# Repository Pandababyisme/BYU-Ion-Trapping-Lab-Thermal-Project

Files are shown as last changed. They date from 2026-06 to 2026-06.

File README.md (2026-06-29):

# BYU-Ion-Trapping-Lab-Thermal-Project
Hi, I am Xiao Li. This is the project I worked on during summer of 2026, which is a thermal monitoring solution for an ion trapping quantum information processing lab. I will provide as detailed steps as I can here. Hopefully, it can be useful one day for you. :)

## 1. Preview
   In an ion trapping lab, different components and machines coperate as a whole to function the state-of-art quantum information process. While this happening, constronted by phsical phnominone, heat drfit will occur. And for our propuse we want to monitor the thermal information to get a better idea of what is going on.

## 2. Solution
   We proposed a solution of a system that consists one arduino, six maxchips, six pt100 sensors, and various supporting parts. In the following, we will step into more detailed description of different components, introductions of the way to make them work, assemble individual parts into a system and mislinious steps of supporting.

### 2.1)Arduino 
As the introduction, we will need one Arduino. The one we used is Arduino UNO R4 minima, personally I think it is a pretty powerful and realiable source for this project. In our solution, an arduino will role as the brain in system, which will suffit the tasks as: data collection, communicating with six maxchips via SPI protocal, transimitting data to our computer, etc. And the way we implement those tasks is through Arduino IDE. By uploading proper code to Arduino, it will perform the way as desired, and complete tasks. So we will include a Arduino IDE code file in this repository as an example of one solution. 

#### 2.11) Code design of the Arduino

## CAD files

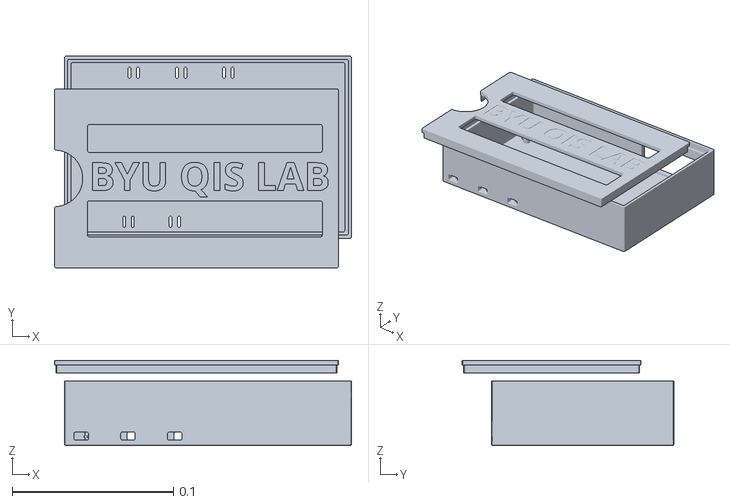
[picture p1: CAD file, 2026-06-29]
Part Studio 1.stl
0.184 x 0.131 x 0.053

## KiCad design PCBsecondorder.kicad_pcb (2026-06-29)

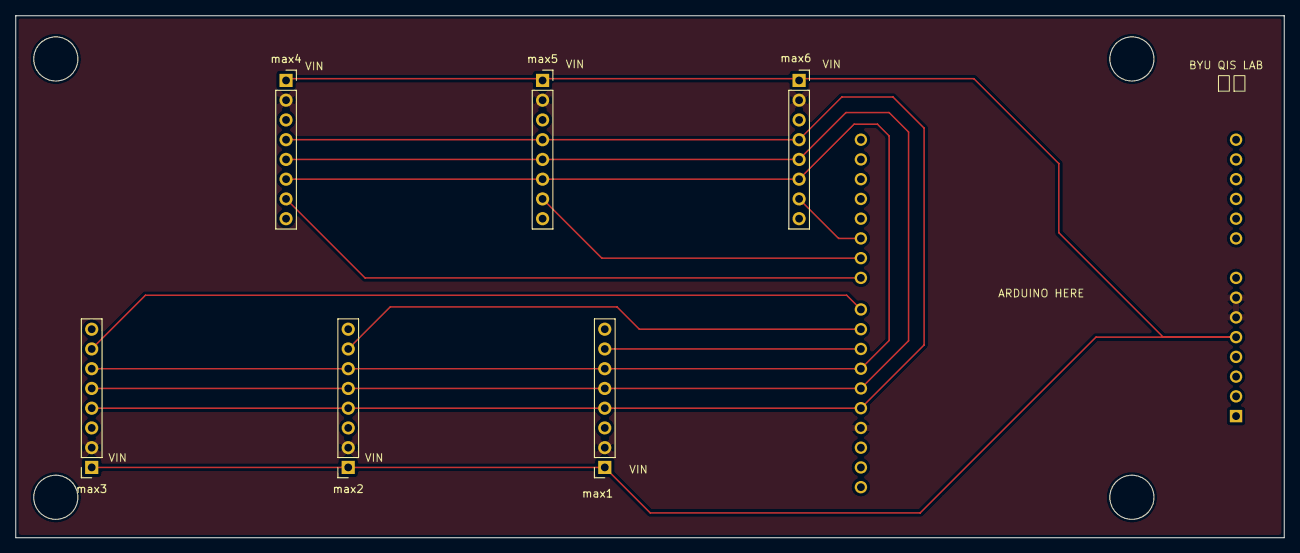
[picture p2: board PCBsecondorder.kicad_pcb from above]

Board: 2 copper layers, 163.2 x 67.1 mm, 7 parts (1 on the bottom side), 11 nets.

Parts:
A1: Arduino_UNO_R4; Arduino_UNO_R3
max1, max2, max3, max4, max5, max6: Conn_01x08; PinSocket_1x08_P2.54mm_Vertical

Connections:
/5V: A1.5 (+5V), max1.1, max2.1, max3.1, max4.1, max5.1, max6.1
/CLK: A1.28 (D13), max1.4, max2.4, max3.4, max4.4, max5.4, max6.4
/CS1: A1.25 (D10), max1.7
/CS2: A1.24 (D9), max2.7
/CS3: A1.23 (D8), max3.7
/CS4: A1.22 (D7), max4.7
/CS5: A1.21 (D6), max5.7
/CS6: A1.20 (D5), max6.7
/GND: A1.6 (GND), A1.7 (GND), A1.29 (GND), max1.2, max2.2, max3.2, max4.2, max5.2, max6.2
/SDI: A1.26 (D11), max1.6, max2.6, max3.6, max4.6, max5.6, max6.6
/SDO: A1.27 (D12), max1.5, max2.5, max3.5, max4.5, max5.5, max6.5

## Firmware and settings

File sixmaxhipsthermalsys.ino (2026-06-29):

#include <Adafruit_MAX31865.h>
#include <SPI.h>

// -------------------------------
// Output mode
// -------------------------------
#define MODE_DEBUG   0
#define MODE_PLOTTER 1
#define MODE_CSV     2

// Choose one mode here:
// MODE_CSV     = output Max1 to Max6 for Python/Excel
// MODE_PLOTTER = show six curves in Serial Plotter
// MODE_DEBUG   = detailed Serial Monitor output
#define OUTPUT_MODE 2

// -------------------------------
// CS pins for the 6 MAX31865 chips
// Sensor 1 -> CS 10
// Sensor 2 -> CS 9
// Sensor 3 -> CS 8
// Sensor 4 -> CS 7
// Sensor 5 -> CS 6
// Sensor 6 -> CS 5
// -------------------------------
const int CS_PINS[6] = {10, 9, 8, 7, 6, 5};

// PT100 settings
#define RREF      430.0
#define RNOMINAL 100.0

// -------------------------------
// Two-point calibration values
// -------------------------------
float refLow = 10.8;
float refHigh = 92.8;

float rawLow[6] = {
  11.66,  // Max1 raw low temp
  11.55,  // Max2 raw low temp
  11.62,  // Max3 raw low temp
  11.66,  // Max4 raw low temp
  11.72,  // Max5 raw low temp
  11.89   // Max6 raw low temp
};

float rawHigh[6] = {
  92.75,  // Max1 raw high temp
  92.65,  // Max2 raw high temp
  92.78,  // Max3 raw high temp
  92.89,  // Max4 raw high temp
  92.27,  // Max5 raw high temp
  92.58   // Max6 raw high temp
};

// Calibration equation:
// calibratedTemp = slope * rawTemp + intercept
float slope[6];
float intercept[6];

// -------------------------------
// Create 6 MAX31865 objects
// -------------------------------
Adafruit_MAX31865 max1 = Adafruit_MAX31865(CS_PINS[0]);
Adafruit_MAX31865 max2 = Adafruit_MAX31865(CS_PINS[1]);
Adafruit_MAX31865 max3 = Adafruit_MAX31865(CS_PINS[2]);
Adafruit_MAX31865 max4 = Adafruit_MAX31865(CS_PINS[3]);
Adafruit_MAX31865 max5 = Adafruit_MAX31865(CS_PINS[4]);
Adafruit_MAX31865 max6 = Adafruit_MAX31865(CS_PINS[5]);

Adafruit_MAX31865* sensors[6] = {
  &max1, &max2, &max3, &max4, &max5, &max6
};

// -------------------------------
// Calculate calibration constants
// -------------------------------
void calculateCalibration() {
  for (int i = 0; i < 6; i++) {
    float denominator = rawHigh[i] - rawLow[i];

    if (denominator > -0.001 && denominator < 0.001) {
      slope[i] = 1.0;
      intercept[i] = 0.0;
    } else {
      slope[i] = (refHigh - refLow) / denominator;
      intercept[i] = refLow - slope[i] * rawLow[i];
    }
  }
}

// -------------------------------
// Calibration function
// -------------------------------
float calibrateTemperature(int index, float rawTemp) {
  return slope[index] * rawTemp + intercept[index];
}

// -------------------------------
// Read calibrated temperature from one MAX31865
// -------------------------------
float readCalibratedTemperature(int index) {
  float rawTemp = sensors[index]->temperature(RNOMINAL, RREF);
  float calTemp = calibrateTemperature(index, rawTemp);
  return calTemp;
}

// -------------------------------
// Fault printing function
// -------------------------------
void printFault(uint8_t fault) {
  if (fault & MAX31865_FAULT_HIGHTHRESH) {
    Serial.print("RTD High Threshold; ");
  }
  if (fault & MAX31865_FAULT_LOWTHRESH) {
    Serial.print("RTD Low Threshold; ");
  }
  if (fault & MAX31865_FAULT_REFINLOW) {
    Serial.print("REFIN- > 0.85 x Bias; ");
  }
  if (fault & MAX31865_FAULT_REFINHIGH) {
    Serial.print("REFIN- < 0.85 x Bias or FORCE- open; ");
  }
  if (fault & MAX31865_FAULT_RTDINLOW) {
    Serial.print("RTDIN- < 0.85 x Bias or FORCE- open; ");
  }
  if (fault & MAX31865_FAULT_OVUV) {
    Serial.print("Under/Over voltage; ");
  }
}

// -------------------------------
// Debug function
// Detailed Serial Monitor output
// -------------------------------
void readOneSensorDebug(int index) {
  Adafruit_MAX31865* sensor = sensors[index];

  uint16_t rtd = sensor->readRTD();

  float ratio = rtd;
  ratio /= 32768.0;

  float resistance = RREF * ratio;
  float rawTemp = sensor->temperature(RNOMINAL, RREF);
  float calTemp = calibrateTemperature(index, rawTemp);

  Serial.print("Max");
  Serial.print(index + 1);

  Serial.print(" | Raw RTD: ");
  Serial.print(rtd);

  Serial.print(" | Ratio: ");
  Serial.print(ratio, 8);

  Serial.print(" | Resistance: ");
  Serial.print(resistance, 3);
  Serial.print(" ohm");

  Serial.print(" | Raw Temp: ");
  Serial.print(rawTemp, 2);
  Serial.print(" C");

  Serial.print(" | Cal Temp: ");
  Serial.print(calTemp, 2);
  Serial.print(" C");

  Serial.print(" | slope: ");
  Serial.print(slope[index], 6);

  Serial.print(" | intercept: ");
  Serial.print(intercept[index], 6);

  uint8_t fault = sensor->readFault();

  if (fault) {
    Serial.print(" | FAULT 0x");
    Serial.print(fault, HEX);
    Serial.print(" | ");
    printFault(fault);
    sensor->clearFault();
  }

  Serial.println();
}

// -------------------------------
// Plot function
// Use this for Arduino Serial Plotter
// -------------------------------
void plotOneSetOfData() {
  for (int i = 0; i < 6; i++) {
    float calTemp = readCalibratedTemperature(i);

    Serial.print("Max");
    Serial.print(i + 1);
    Serial.print(":");
    Serial.print(calTemp, 2);

    if (i < 5) {
      Serial.print("\t");
    } else {
      Serial.println();
    }
  }
}

// -------------------------------
// CSV function
// Use this for Python/Excel
// Output sequence: Max1, Max2, Max3, Max4, Max5, Max6
// -------------------------------
void printCSVHeader() {
  Serial.println("Max1,Max2,Max3,Max4,Max5,Max6");
}

void storeOneSetOfDataCSV() {
  for (int i = 0; i < 6; i++) {
    float calTemp = readCalibratedTemperature(i);

    Serial.print(calTemp, 2);

    if (i < 5) {
      Serial.print(",");
    } else {
      Serial.println();
    }
  }
}

// -------------------------------
// Setup
// -------------------------------
void setup() {
  Serial.begin(9600);
  delay(1000);

  // Set every CS pin HIGH before starting
  for (int i = 0; i < 6; i++) {
    pinMode(CS_PINS[i], OUTPUT);
    digitalWrite(CS_PINS[i], HIGH);
  }

  SPI.begin();

  // Use this for 3-wire PT100 sensors
  for (int i = 0; i < 6; i++) {
    sensors[i]->begin(MAX31865_3WIRE);
  }

  calculateCalibration();

  if (OUTPUT_MODE == MODE_DEBUG) {
    Serial.println();
    Serial.println("Six MAX31865 PT100 calibrated test starting...");
    Serial.println("Baud rate: 9600");
    Serial.println("Debug mode");
    Serial.println("Setup complete.");
    Serial.println();
  }

  if (OUTPUT_MODE == MODE_CSV) {
    printCSVHeader();
  }
}

// -------------------------------
// Main loop
// -------------------------------
void loop() {
  if (OUTPUT_MODE == MODE_CSV) {
    storeOneSetOfDataCSV();
    delay(500);
  }

  else if (OUTPUT_MODE == MODE_PLOTTER) {
    plotOneSetOfData();
    delay(500);
  }

  else if (OUTPUT_MODE == MODE_DEBUG) {
    static int readingNumber = 0;
    readingNumber++;

    Serial.print("Reading ");
    Serial.println(readingNumber);

    for (int i = 0; i < 6; i++) {
      readOneSensorDebug(i);
      delay(100);
    }

    Serial.println();
    delay(1000);
  }
}

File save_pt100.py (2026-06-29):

import serial
import time
from datetime import datetime
from pathlib import Path

PORT = "COM4"
BAUD = 9600

SAMPLE_INTERVAL_SECONDS = 30 * 60   # 30 minutes

filename = Path(__file__).with_name("pt100_data.csv")

print("Starting PT100 data logger...")
print("Port:", PORT)
print("Baud:", BAUD)
print("Output file:", filename)
print("Sampling once every 30 minutes.")
print("Opening serial port...")

try:
    ser = serial.Serial(PORT, BAUD, timeout=2)
except Exception as e:
    print("ERROR: Could not open serial port.")
    print(e)
    print()
    print("Make sure Arduino Serial Monitor and Serial Plotter are closed.")
    raise SystemExit

time.sleep(2)

print("Serial port opened.")
print("It will keep recording until you press Ctrl+C.")
print()

try:
    with open(filename, "a", newline="") as file:
        while True:
            print("Taking one sample now...")

            # Read until we get a real data line
            line = ""
            while not line:
                line = ser.readline().decode("utf-8", errors="ignore").strip()

            real_time = datetime.now().strftime("%Y-%m-%d %H:%M:%S.%f")[:-3]
            new_line = real_time + "," + line

            print(new_line)
            file.write(new_line + "\n")
            file.flush()

            print("One sample saved. Waiting 30 minutes...")
            print()

            time.sleep(SAMPLE_INTERVAL_SECONDS)

except KeyboardInterrupt:
    print()
    print("Recording stopped by user.")

finally:
    ser.close()
    print("Serial port closed.")
    print("Data saved to:", filename)

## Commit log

2026-06-29 Enhance README with project and solution details
    Expanded the README with project overview, solution details, and Arduino introduction.
2026-06-29 Add files via upload
    This is our design of PCB
    [PCBsecondorder.kicad_pcb]
2026-06-29 3D printed case with lid
    [Part Studio 1.stl]
